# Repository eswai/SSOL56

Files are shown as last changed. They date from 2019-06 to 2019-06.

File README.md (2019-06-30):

# 分割キーボードSSOL56

SSOL56は左右分割型の56キーのキーボードです。いろいろなコンセプトの検証のために作ったキーボードです。

## 特徴

- biacco42氏提唱のModuloアーキテクチャに準拠しています。ただし無線化には対応しません。
- Otholinearレイアウトをベースにしていますが、親指キーは自然に打てるレイアウトに変更しました。
- 一般的な19mmピッチより狭いキーピッチを試すために、ロープロファイルキースイッチとキーキャップを使用して、横18mm、縦17mmピッチで配置しています。Helix Picoと同じです。

## 設計

- biacco42氏のリファレンス設計を基にしており、使用している部品もTCA9555など、ほぼ同じです。
- Moduloアーキテクチャに忠実に従えば、TRRSはINT信号も含めた2個で1セットですが、今回は無線化する予定はなく、スペースも限られているので、INT信号は省略しました。
- Kailh low profileスイッチ専用です。ソケットに対応しています。
- 設計を容易にするためリバーシブル基板はやめ、また左右の基板を共通にするため、キーレイアウトは左右対称にしました。

## 写真

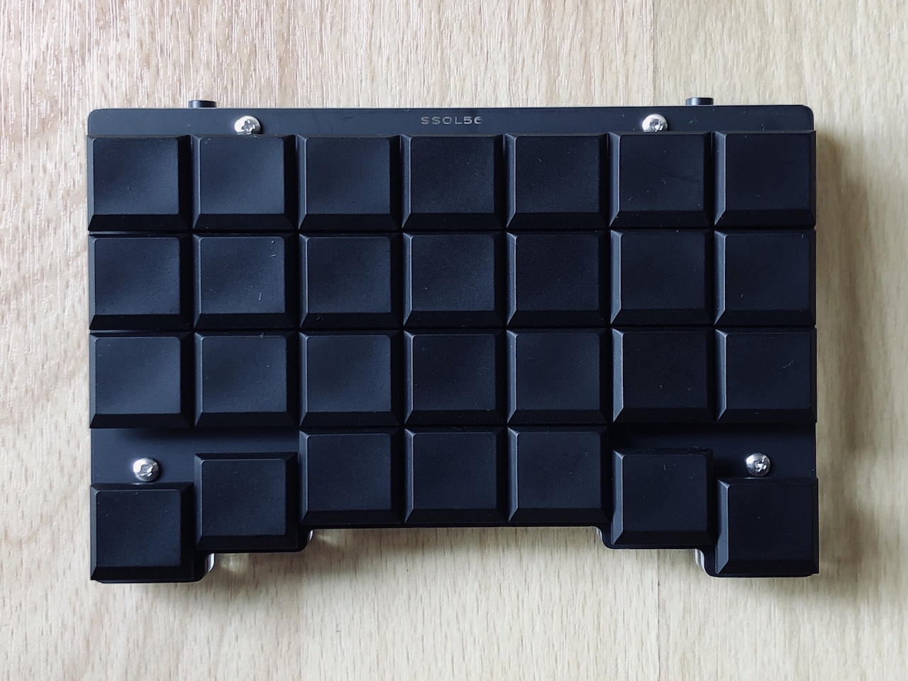
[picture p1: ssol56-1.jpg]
SSOL56

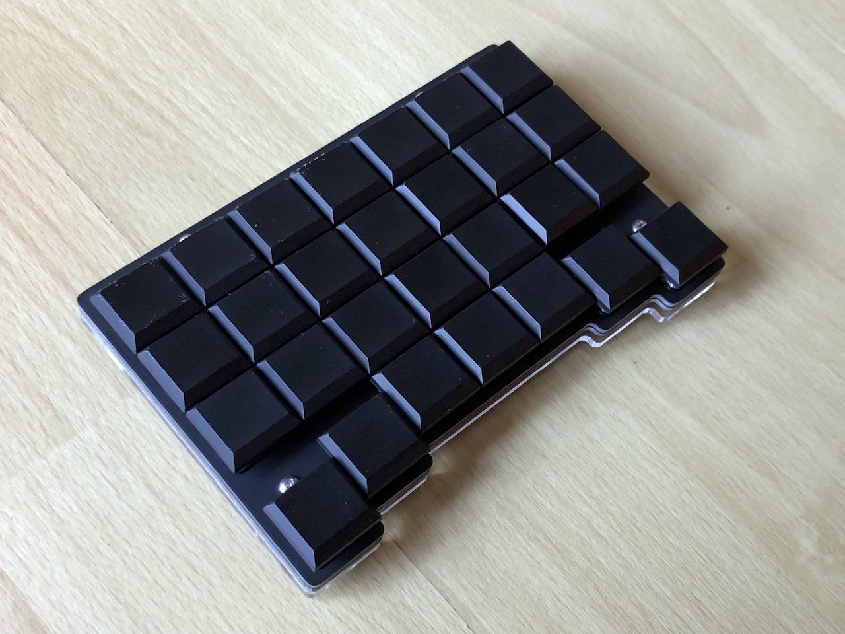
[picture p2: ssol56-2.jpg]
SSOL56

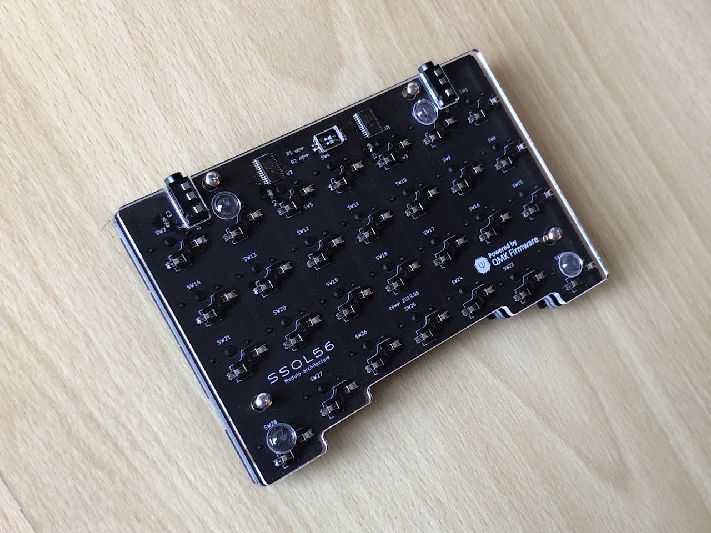
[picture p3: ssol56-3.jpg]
SSOL56

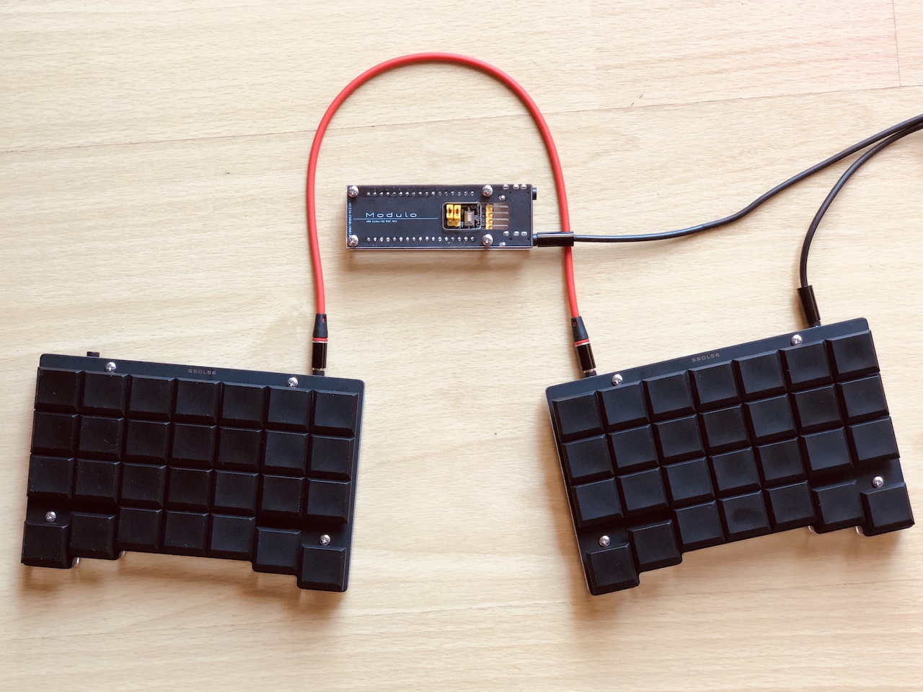
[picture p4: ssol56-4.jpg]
SSOL56


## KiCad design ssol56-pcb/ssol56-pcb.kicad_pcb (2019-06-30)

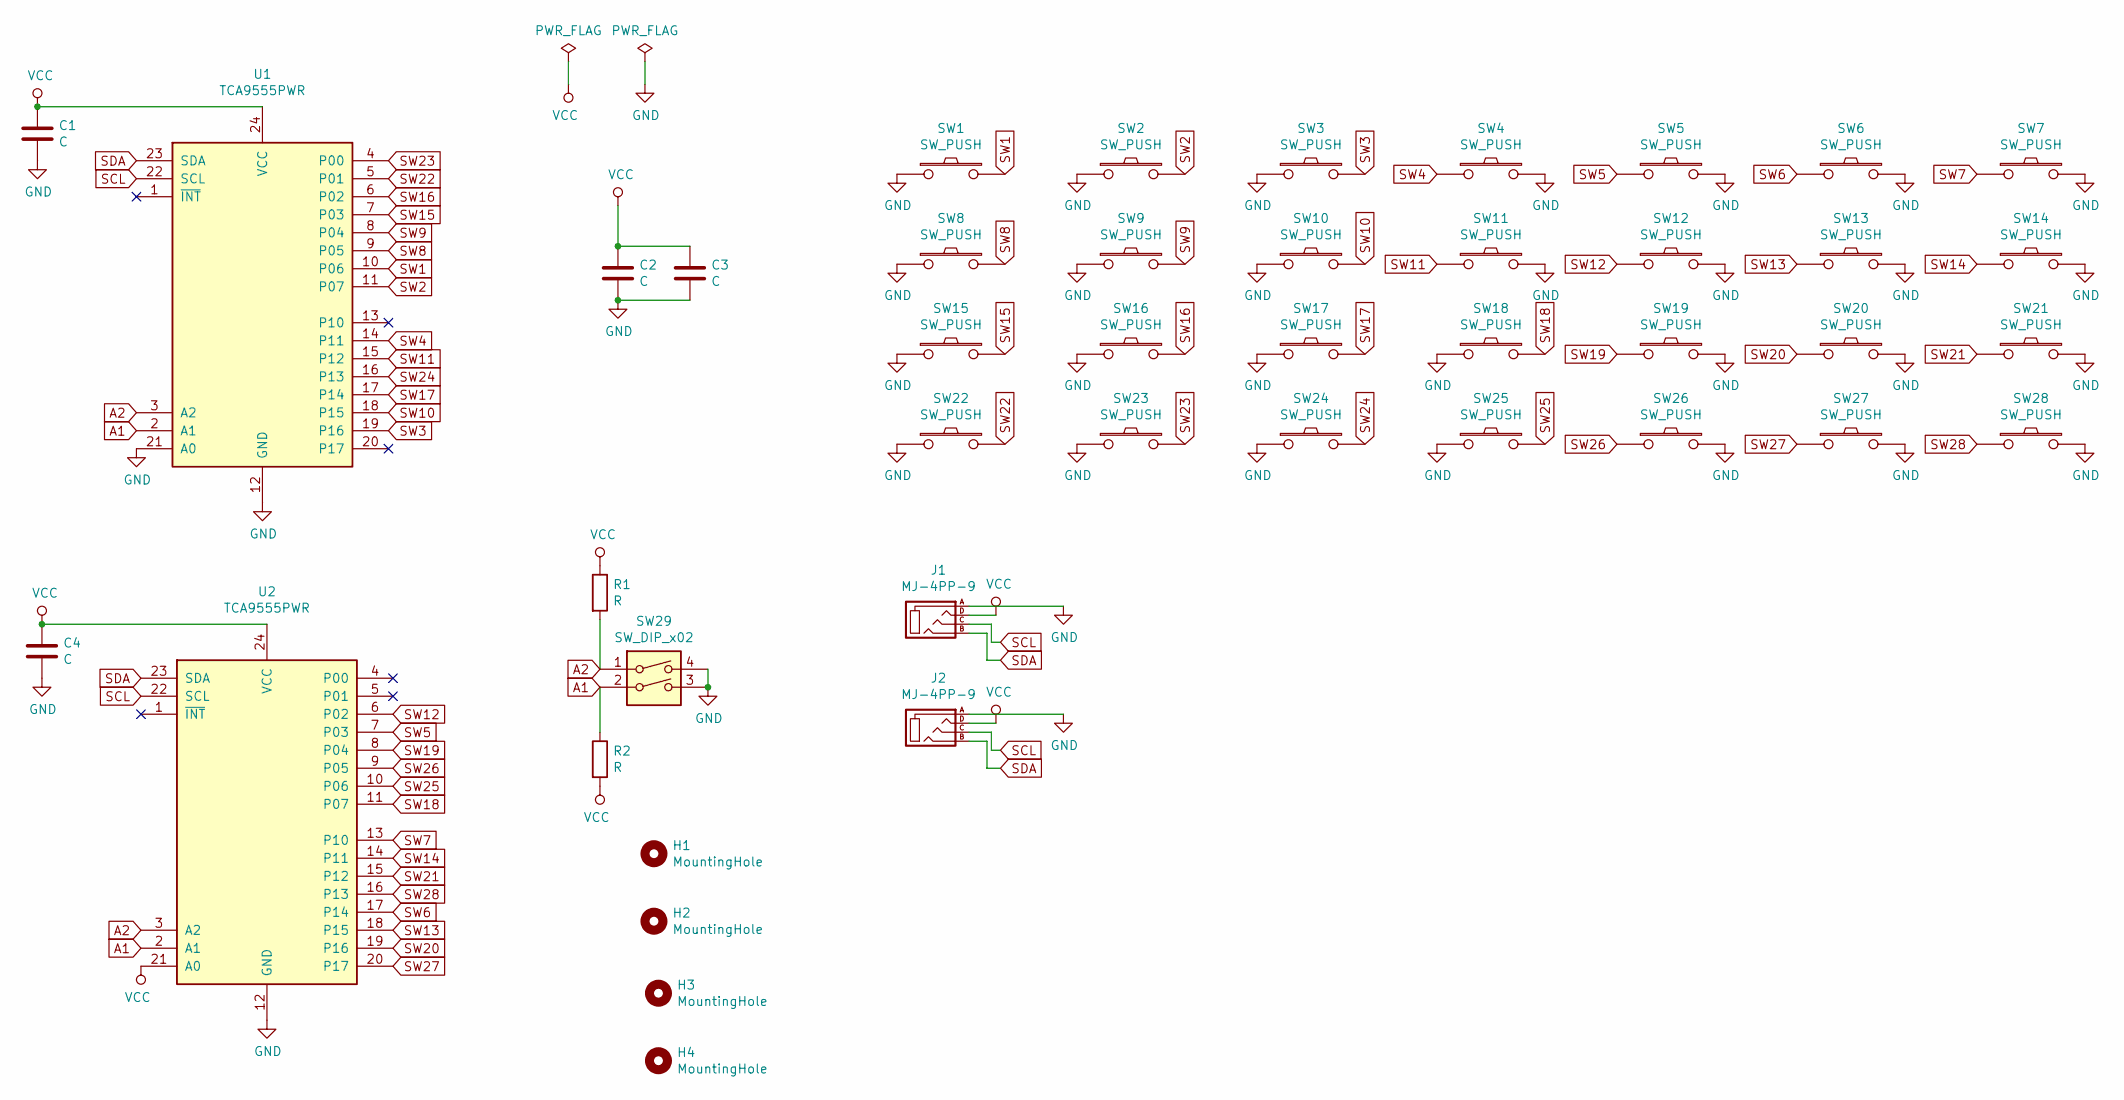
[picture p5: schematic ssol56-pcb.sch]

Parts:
C1, C2, C3, C4: C; C_0603_1608Metric_Pad1.05x0.95mm_HandSolder
H1, H2, H3, H4: MountingHole; HOLE
J1, J2: MJ-4PP-9; TRRS_SMD_PJ320_single
R1, R2: R; R_0603_1608Metric_Pad1.05x0.95mm_HandSolder
SW1, SW2, SW3, SW4, SW5, SW6, SW7, SW8, SW9, SW10, SW11, SW12, SW13, SW14, SW15, SW16, SW17, SW18, SW19, SW20, SW21, SW22, SW23, SW24, SW25, SW26, SW27, SW28: SW_PUSH; CherryMX_Choc_Hotswap_copy
SW29: SW_DIP_x02; DipSwitch
U1, U2: TCA9555PWR; TSSOP-24_4.4x7.8mm_P0.65mm

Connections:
A1: R2.1, SW29.2, U1.2 (A1), U2.2 (A1)
A2: R1.2, SW29.1, U1.3 (A2), U2.3 (A2)
GND: C1.2, C2.2, C3.2, C4.2, J1.A, J2.A, SW1.1, SW2.1, SW3.1, SW4.2, SW5.2, SW6.2, SW7.2, SW8.1, SW9.1, SW10.1, SW11.2, SW12.2, SW13.2, SW14.2, SW15.1, SW16.1, SW17.1, SW18.1, SW19.2, SW20.2, SW21.2, SW22.1, SW23.1, SW24.1, SW25.1, SW26.2, SW27.2, SW28.2, SW29.3, SW29.4, U1.12 (GND), U1.21 (A0), U2.12 (GND)
SCL: J1.C, J2.C, U1.22 (SCL), U2.22 (SCL)
SDA: J1.B, J2.B, U1.23 (SDA), U2.23 (SDA)
SW1: SW1.2, U1.10 (P06)
SW2: SW2.2, U1.11 (P07)
SW3: SW3.2, U1.19 (P16)
SW4: SW4.1, U1.14 (P11)
SW5: SW5.1, U2.7 (P03)
SW6: SW6.1, U2.17 (P14)
SW7: SW7.1, U2.13 (P10)
SW8: SW8.2, U1.9 (P05)
SW9: SW9.2, U1.8 (P04)
SW10: SW10.2, U1.18 (P15)
SW11: SW11.1, U1.15 (P12)
SW12: SW12.1, U2.6 (P02)
SW13: SW13.1, U2.18 (P15)
SW14: SW14.1, U2.14 (P11)
SW15: SW15.2, U1.7 (P03)
SW16: SW16.2, U1.6 (P02)
SW17: SW17.2, U1.17 (P14)
SW18: SW18.2, U2.11 (P07)
SW19: SW19.1, U2.8 (P04)
SW20: SW20.1, U2.19 (P16)
SW21: SW21.1, U2.15 (P12)
SW22: SW22.2, U1.5 (P01)
SW23: SW23.2, U1.4 (P00)
SW24: SW24.2, U1.16 (P13)
SW25: SW25.2, U2.10 (P06)
SW26: SW26.1, U2.9 (P05)
SW27: SW27.1, U2.20 (P17)
SW28: SW28.1, U2.16 (P13)
VCC: C1.1, C2.1, C3.1, C4.1, J1.D, J2.D, R1.1, R2.2, U1.24 (VCC), U2.21 (A0), U2.24 (VCC)

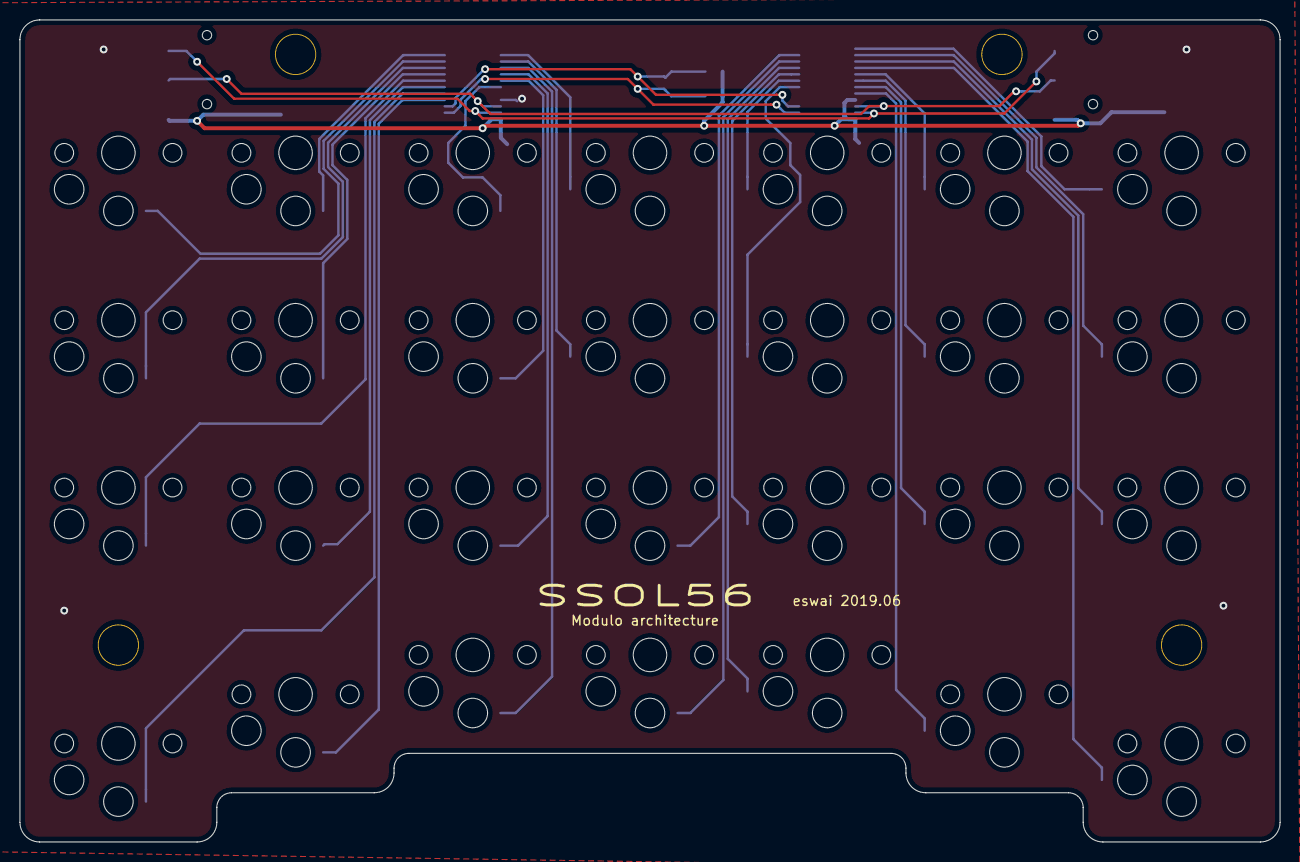
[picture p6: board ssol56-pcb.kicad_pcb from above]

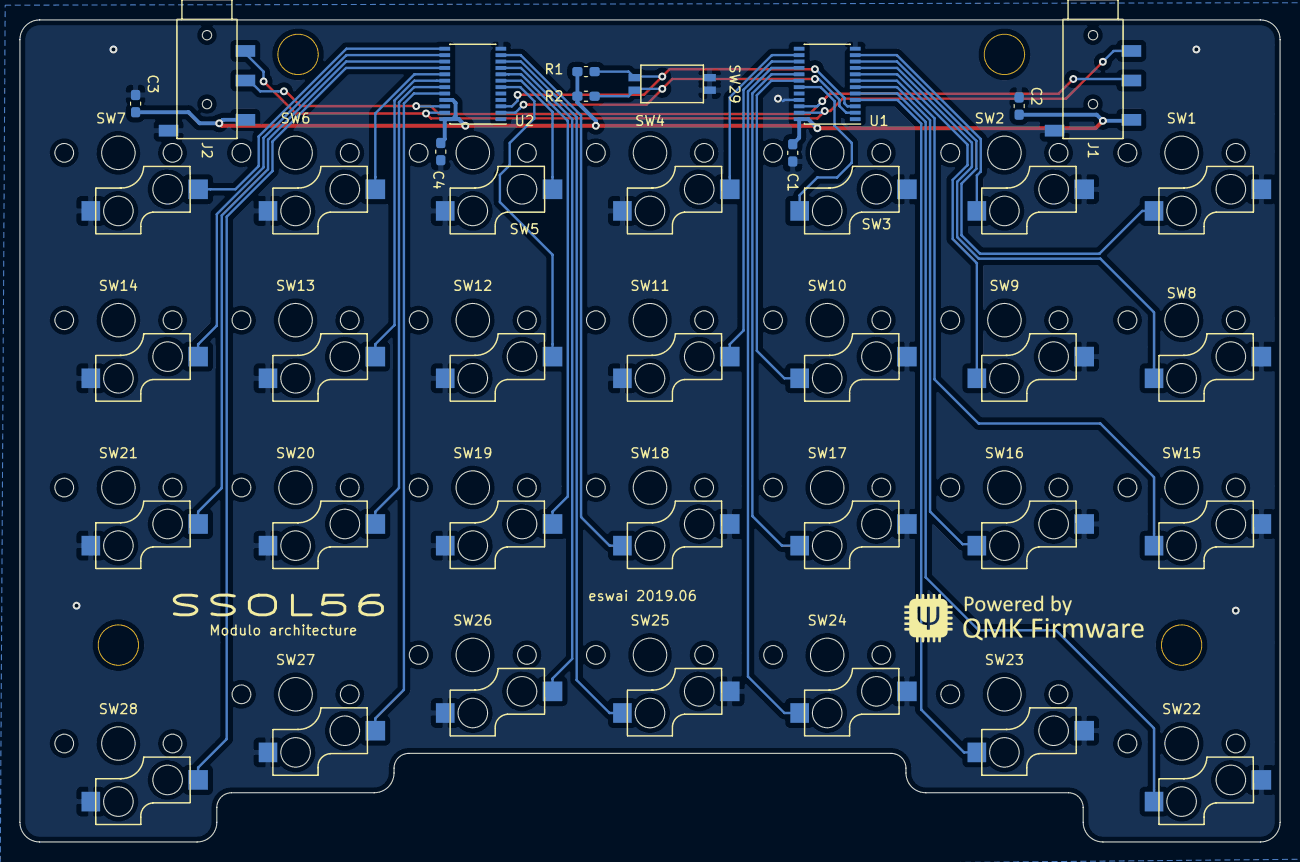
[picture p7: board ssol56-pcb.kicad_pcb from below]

Board: 2 copper layers, 128.0 x 83.5 mm, 43 parts (11 on the bottom side), 34 nets.
